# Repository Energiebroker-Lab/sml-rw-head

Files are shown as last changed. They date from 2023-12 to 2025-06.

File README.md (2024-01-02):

# sml-rw-head
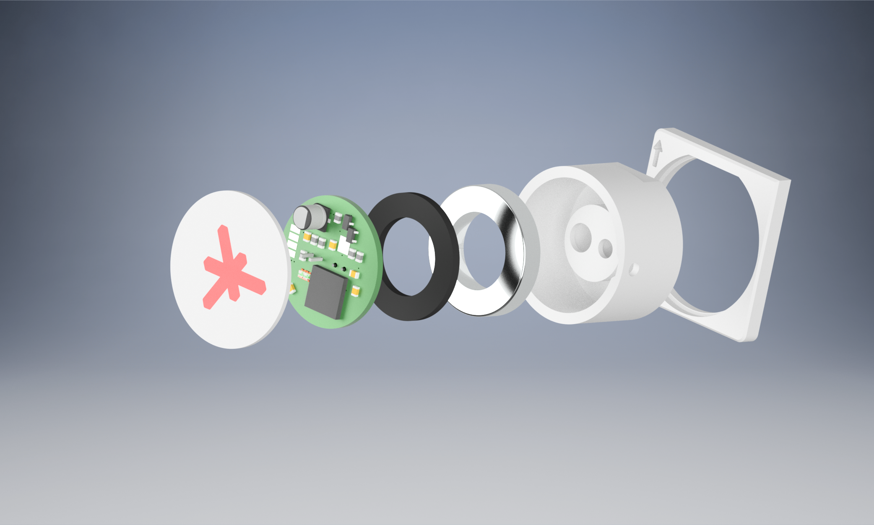
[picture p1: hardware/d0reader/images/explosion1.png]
explosion

## Overview

**sml-rw-head** is a versatile read-write module designed to attach to power meters via a magnet.
It reads the SML (Smart Message Language) or ODT stream from the D0 interface of the meter.
Additionally, the device is equipped to send pulses for entering the PIN or navigating through the menu of the meter
and for example toggle the info mode.

This project encompasses three main components:

1. **Hardware:** Includes schematics and PCB (Printed Circuit Board) designs.
2. **3D-Printable Parts:** Consists of printable components that complement the hardware.
3. **Code:** The code is an implementation example
of the sml-rw-head device.

Each major component has its dedicated directory with its own README.md for detailed information.

## Project Structure

- **Hardware:** The hardware files are located in the `./hardware/d0reader` subdirectory. Refer to the [Hardware README](./hardware/d0reader/README.md) for specifics.

- **3D-Printable Parts:** Find 3D-printable files in the `./hardware/3d-print` subdirectory. More details are available in the [3D-Print README](./hardware/3d-print/README.md).

- **Code:** The source code is in the `./code/sml_rw` subdirectory. To get started with the code, please check the [Code README](./code/sml_rw/README.md).

## Usage

Before using the sml-rw-head module, make sure to review the documentation for each component. Follow the guidelines provided in the respective READMEs for successful integration into your project.

### Preparation
Before using the sml-rw-head module, you need to configure the device using the `ftprog_template.xml` file. Import the file and perform the configuration using the [ftprog](https://ftdichip.com/utilities/) software supplied by FTDI.

## Contributions

Contributions to the sml-rw-head project are welcome! If you have ideas, improvements, or bug fixes, please feel free to submit issues or pull requests.

## License

This project is licensed under the [MIT License](LICENSE). See the LICENSE file for more details.

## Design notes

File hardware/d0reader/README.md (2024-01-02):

Based on https://www.stefan-weigert.de/php_loader/sml.php

# BOM
| Part | Value | Device | Package | Description |
|---|---|---|---|---|
| C1 | 100n | Capacitor | 0805 | Capacitor, Ceramic |
| C2 | 100n | Capacitor | 0805 | Capacitor, Ceramic |
| C3 | 100n | Capacitor | 0805 | Capacitor, Ceramic |
| C4 | 1u | Capacitor | 0805 | Capacitor, Ceramic |
| C5 | 1u | Capacitor | 0805 | Capacitor, Ceramic |
| C6 | 22u | EEEHA1C220R | CPOL-EU153CLV-0505  | 153CLV-0505 POLARIZED CAPACITOR |
| IC1  | FT232RL | FT232RL | SSOP28 | Source: http://www.ftdichip.com/Documents/DataSheets/DS_FT232R_v104.pdf | 
| LED1 | KCL5587S | LED5MM | LED5MM | Infrared-Emitter | 
| LED2 | LEDCHIPLED_0805 | CHIPLED | 0805 | LED (optional) | 
| LED3 | LEDCHIPLED_0805 | CHIPLED | 0805 | LED (optional) | 
| PAD1 | | WIREPADSMD1,27-254 | SMD1,27-2,54 | Wire PAD connect wire on PCB | 
| PAD2 | | WIREPADSMD1,27-254 | SMD1,27-2,54 | Wire PAD connect wire on PCB | 
| PAD3 | | WIREPADSMD1,27-254 | SMD1,27-2,54 | Wire PAD connect wire on PCB | 
| PAD4 | | WIREPADSMD1,27-254 | SMD1,27-2,54 | Wire PAD connect wire on PCB | 
| Q1 | BC817 | BC817-16LT1SMD | SOT23-BEC | NPN Transistor | NPN Transistor | 
| Q2 | SFH_309_FA-4/5  | SFH_309_FA-4/5 | XDCR_SFH_309_FA-4/5 | Phototransistor IR Chip Silicon 900nm 2-Pin T-1 Check prices |
| Q3 | BC817 | BC817-16LT1SMD | SOT23-BEC | NPN Transistor | 
| Q4 | BC817 | BC817-16LT1SMD | SOT23-BEC | NPN Transistor | 
| R1 | 220 | Resistor | 0805 | Resistor |
| R2 | 220 | Resistor | 0805 | Resistor | 
| R3 | 12k | Resistor | 0805 | Resistor | 
| R4 | 12k | Resistor | 0805 | Resistor | 
| R5 | 75 | Resistor | 0805 | Resistor | 
| R6 | 220 | Resistor | 0805 | Resistor | 
| R7 | 220 | Resistor | 0805 | Resistor | 
| U4 | SN74LVC1G17DBVR | Schmitt-Trigger | SOT-23 | Schmitt-Trigger |

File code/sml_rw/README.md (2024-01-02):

TODO: update readmy (new commands + odt)

# sml-reader
Implementation example to read the sml (and odt) data via the d0 interface.

@Python 3.11
# CLI
## Detect 
### all ftdi devices
```commandline
python run.py detect all
```
### single ftdi device
```commandline
python run.py detect serial ftdiSerial
foo@bar:~$ python run.py detect serial EB1337051
```
## Meter
```<meter> => mt681, mt175, ehz, easy, dd3_sml, dd3_sml_2way, dd3_odt, dd3_odt_2way```
### log bytes to file
```commandline
python run.py <meter> log_bytes ftdiSerial
foo@bar:~$ python run.py mt175 log_bytes EB1337051
``` 
### log sml to cli
```commandline
python run.py <meter> log_cli ftdiSerial
foo@bar:~$ python run.py mt175 log_cli EB1337051
``` 
### log sml to file
```commandline
python run.py <meter> log_sml ftdiSerial
foo@bar:~$ python run.py mt175 log_sml EB1337051
``` 
### enter pin
```commandline
python run.py <meter> pin ftdiSerial pin
foo@bar:~$ python run.py mt175 pin EB1337051 [1,2,3,4]
``` 
### clear history data (only dd3 and easy meters)
#### topics
* e
* his
```commandline
python run.py <meter> clear ftdiSerial pin topic
foo@bar:~$ python run.py dd3 clear EB1337051 [1,2,3,4] e
``` 
### show (only dd3 and easy meters)
#### topics
* e
* 1d
* 7d
* 30d
* 365d
* info
* p
* pin
```commandline
python run.py <meter> show ftdiSerial pin topic
foo@bar:~$ python run.py dd3 show EB1337051 [1,2,3,4] e
``` 
### toggle (only dd3 and easy meters)
#### topics
* info
* p
* pin
```commandline
python run.py <meter> toggle ftdiSerial pin topic
foo@bar:~$ python run.py dd3 toggle EB1337051 [1,2,3,4] info
``` 
### interactive mode
#### interactive commands
* short pulse -> .
* long pulse -> -
* pause -> _space_
* quit interactive mode -> exit
```commandline
python run.py <meter> interactive ftdiSerial pin
foo@bar:~$ python run.py dd3 interactive EB1337051 [1,2,3,4]
```

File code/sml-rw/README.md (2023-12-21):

# sml-reader
Implementation example to read the sml data via the d0 interface. Sample data included.

@Python 3.9
# cli
## detect 
### all ftdi devices
```commandline
python run.py detect all
```
### single ftdi device
```commandline
python run.py detect serial ftdiSerial
foo@bar:~$ python run.py detect serial EB_DE_PROT_3
```
## Meter: mt175
### log bytes to file
```commandline
python run.py mt175 logBytes ftdiSerial
foo@bar:~$ python run.py mt175 logBytes EB_DE_PROT_3
``` 
### log sml to cli
```commandline
python run.py mt175 logCli ftdiSerial
foo@bar:~$ python run.py mt175 logCli EB_DE_PROT_3
``` 
### log sml to file
```commandline
python run.py mt175 logSml ftdiSerial
foo@bar:~$ python run.py mt175 logSml EB_DE_PROT_3
``` 
### enter pin
```commandline
python run.py mt175 pin ftdiSerial pin
foo@bar:~$ python run.py mt175 pin EB_DE_PROT_3 [1,2,3,4]
``` 
## Meter: mt681
### log bytes to file
```commandline
python run.py mt681 logBytes ftdiSerial
foo@bar:~$ python run.py mt681 logBytes EB_DE_PROT_3
``` 
### log sml to cli
```commandline
python run.py mt681 logCli ftdiSerial
foo@bar:~$ python run.py mt681 logCli EB_DE_PROT_3
``` 
### log sml to file
```commandline
python run.py mt681 logSml ftdiSerial
foo@bar:~$ python run.py mt681 logSml EB_DE_PROT_3
``` 
### enter pin
```commandline
python run.py mt681 pin ftdiSerial pin
foo@bar:~$ python run.py mt681 pin EB_DE_PROT_3 [1,2,3,4]
``` 
## Meter: ehz
### log bytes to file
```commandline
python run.py ehz logBytes ftdiSerial
foo@bar:~$ python run.py ehz logBytes EB_DE_PROT_3
``` 
### log sml to cli
```commandline
python run.py ehz logCli ftdiSerial
foo@bar:~$ python run.py ehz logCli EB_DE_PROT_3
``` 
### log sml to file
```commandline
python run.py ehz logSml ftdiSerial
foo@bar:~$ python run.py ehz logSml EB_DE_PROT_3
``` 
### enter pin
```commandline
python run.py ehz pin ftdiSerial pin
foo@bar:~$ python run.py ehz pin EB_DE_PROT_3 [1,2,3,4]
``` 
## Meter: dd3
### log bytes to file
```commandline
python run.py dd3 logBytes ftdiSerial
foo@bar:~$ python run.py dd3 logBytes EB_DE_PROT_3
``` 
### log sml to cli
```commandline
python run.py dd3 logCli ftdiSerial
foo@bar:~$ python run.py dd3 logCli EB_DE_PROT_3
``` 
### log sml to file
```commandline
python run.py dd3 logSml ftdiSerial
foo@bar:~$ python run.py dd3 logSml EB_DE_PROT_3
``` 
### enter pin
```commandline
python run.py dd3 pin ftdiSerial pin
foo@bar:~$ python run.py dd3 pin EB_DE_PROT_3 [1,2,3,4]
``` 
### clear history data
#### topics
* e
* his
```commandline
python run.py dd3 clear ftdiSerial pin topic
foo@bar:~$ python run.py dd3 clear EB_DE_PROT_3 [1,2,3,4] e
``` 
### show
#### topics
* e
* 1d
* 7d
* 30d
* 365d
* info
* p
* pin
```commandline
python run.py dd3 show ftdiSerial pin topic
foo@bar:~$ python run.py dd3 show EB_DE_PROT_3 [1,2,3,4] e
``` 
### toggle
#### topics
* info
* p
* pin
```commandline
python run.py dd3 toggle ftdiSerial pin topic
foo@bar:~$ python run.py dd3 toggle EB_DE_PROT_3 [1,2,3,4] info
``` 
### interactive mode
#### interactive commands
* short pulse -> .
* long pulse -> -
* pause -> _space_
* quit interactive mode -> exit
```commandline
python run.py dd3 interactive ftdiSerial pin
foo@bar:~$ python run.py dd3 interactive EB_DE_PROT_3 [1,2,3,4]
``` 
## Meter: EasyMeter
### log bytes to file
```commandline
python run.py easy logBytes ftdiSerial
foo@bar:~$ python run.py easy logBytes EB_DE_PROT_3
``` 
### log sml to cli
```commandline
python run.py easy logCli ftdiSerial
foo@bar:~$ python run.py easy logCli EB_DE_PROT_3
``` 
### log sml to file
```commandline
python run.py easy logSml ftdiSerial
foo@bar:~$ python run.py easy logSml EB_DE_PROT_3
``` 
### enter pin
```commandline
python run.py easy pin ftdiSerial pin
foo@bar:~$ python run.py easy pin EB_DE_PROT_3 [1,2,3,4]
``` 
### clear history data
#### topics
* e
* his
```commandline
python run.py easy clear ftdiSerial pin topic
foo@bar:~$ python run.py easy clear EB_DE_PROT_3 [1,2,3,4] e
``` 
### show
#### topics
* e
* 1d
* 7d
* 30d
* 365d
* info
* p
* pin
```commandline
python run.py easy show ftdiSerial pin topic
foo@bar:~$ python run.py easy show EB_DE_PROT_3 [1,2,3,4] e
``` 
### toggle
#### topics
* info
* p
* pin
```commandline
python run.py easy toggle ftdiSerial pin topic
foo@bar:~$ python run.py easy toggle EB_DE_PROT_3 [1,2,3,4] info
``` 
### interactive mode
#### interactive commands
* short pulse -> .
* long pulse -> -
* pause -> _space_
* quit interactive mode -> exit
```commandline
python run.py easy interactive ftdiSerial pin
foo@bar:~$ python run.py easy interactive EB_DE_PROT_3 [1,2,3,4]
```

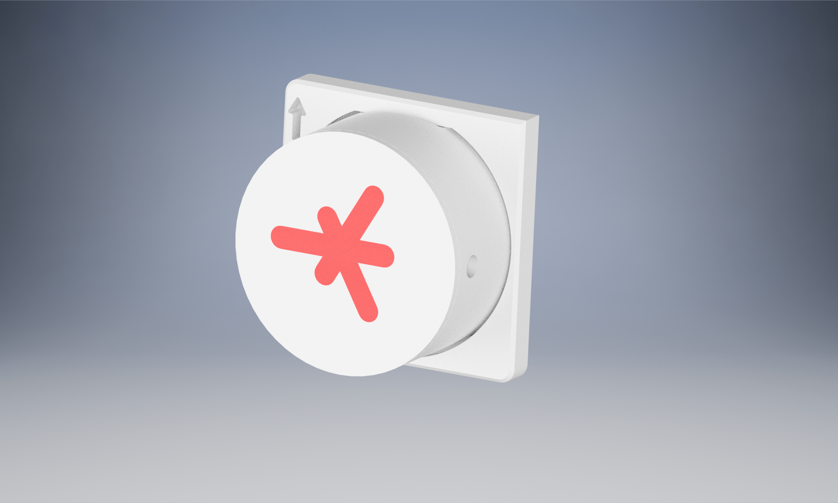
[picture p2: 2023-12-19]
hardware/d0reader/images/front.png

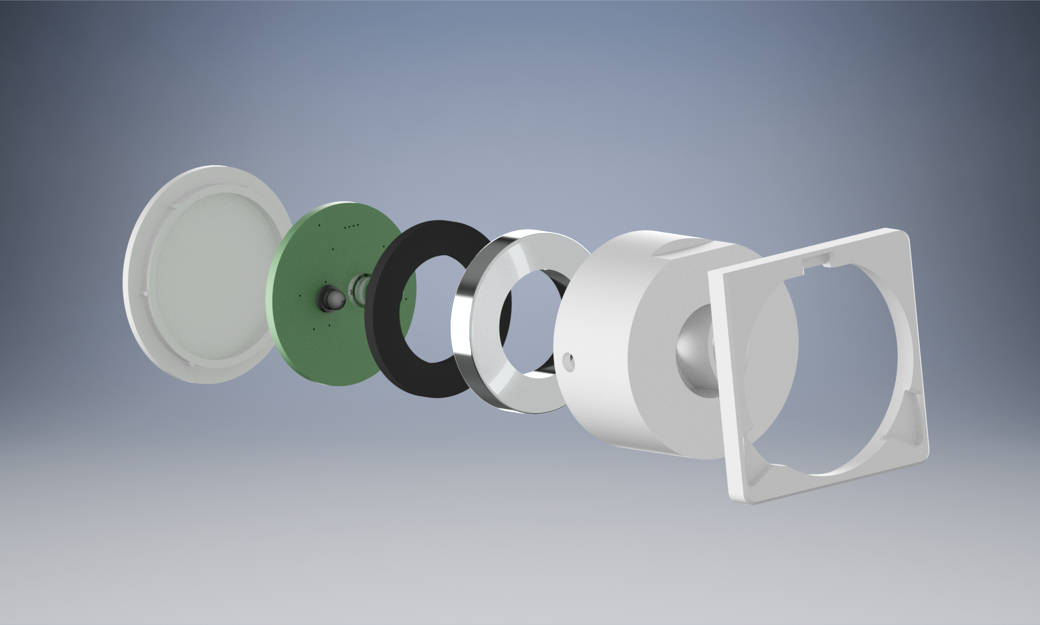
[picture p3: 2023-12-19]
hardware/d0reader/images/explosion2.png

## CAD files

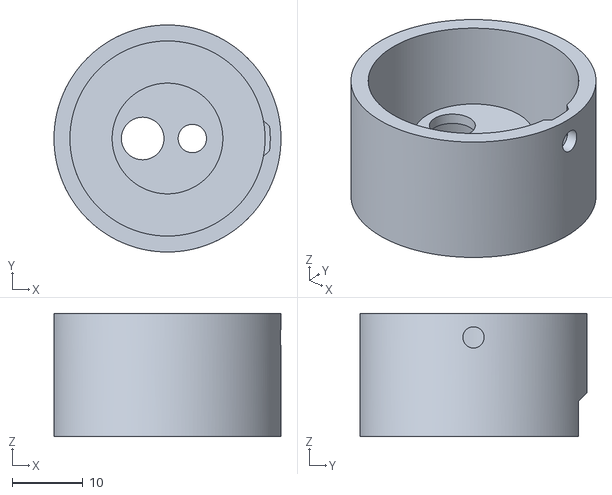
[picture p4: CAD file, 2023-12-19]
hardware/3d-print/case/body.stl
32.0 x 32.0 x 17.4

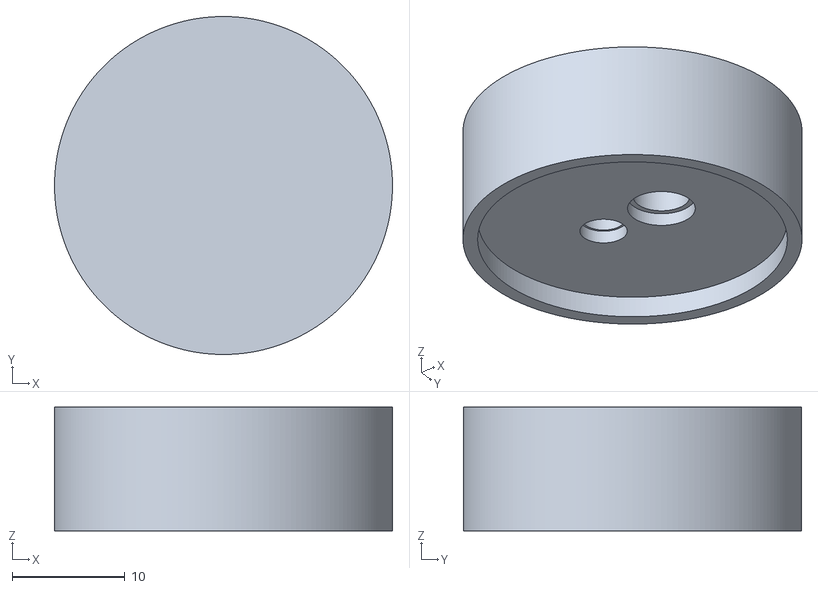
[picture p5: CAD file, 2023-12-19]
hardware/3d-print/depth_stencil.stl
30.0 x 30.0 x 11.0

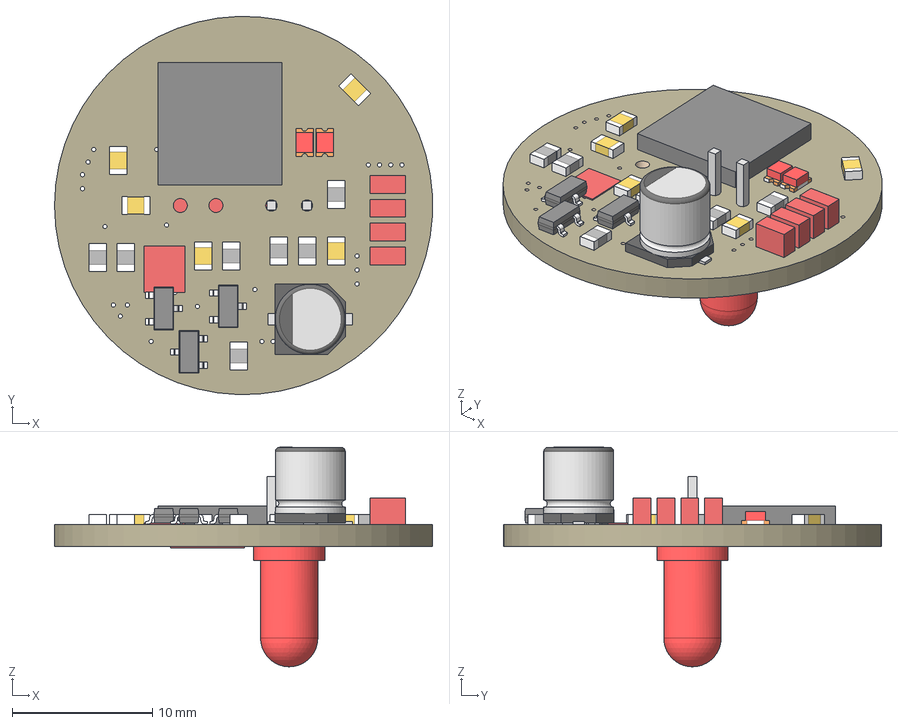
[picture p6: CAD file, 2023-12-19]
hardware/d0reader/3d/d0reader.stp
27.0 x 27.0 x 15.7 mm
Board
100n x 5
KCL5587S
CHIPLED_0805 x 2
SFH_309_FA-4/5
22u EEEHA1C220R
BC817-16LT1SMD x 3
SN74LVC1G17DBVR
FT232RL
WIREPADSMD1,27-254 x 4

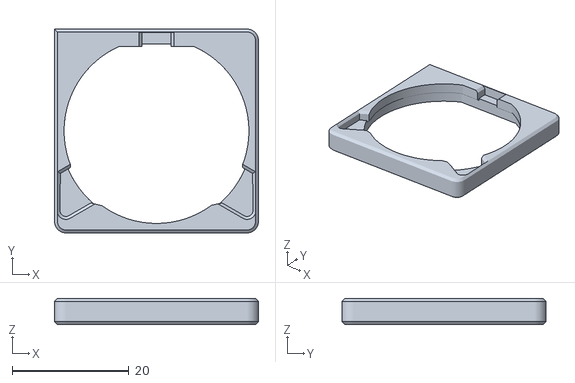
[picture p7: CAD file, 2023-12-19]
hardware/3d-print/case/centering_aid.stl
35.0 x 35.0 x 4.50

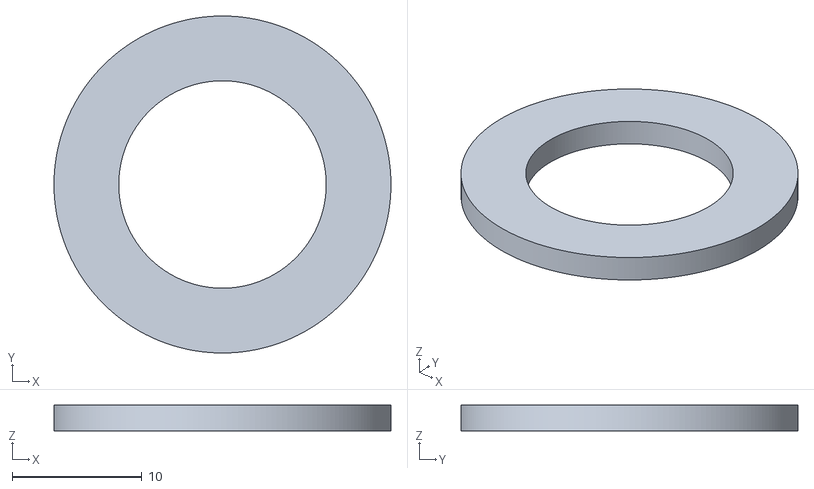
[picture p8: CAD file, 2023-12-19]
hardware/3d-print/case/spacer.stl
26.0 x 26.0 x 2.00

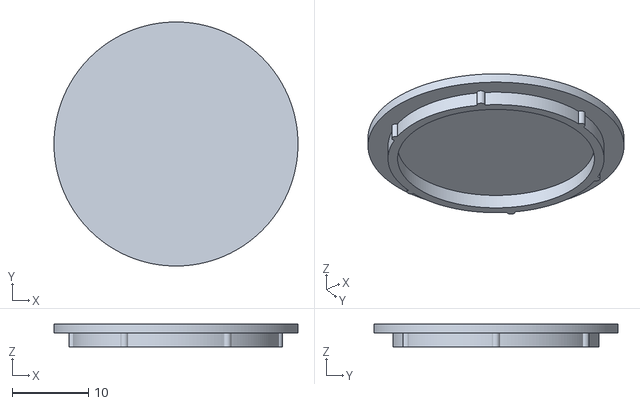
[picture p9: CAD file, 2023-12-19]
hardware/3d-print/case/lid.stl
32.0 x 32.0 x 3.00

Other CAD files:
hardware/3d-print/case/body.ipt
hardware/3d-print/case/centering_aid.ipt
hardware/3d-print/case/lid.ipt
hardware/3d-print/case/spacer.ipt
hardware/3d-print/depth_stencil.ipt
hardware/d0reader/3d/d0reader.stl

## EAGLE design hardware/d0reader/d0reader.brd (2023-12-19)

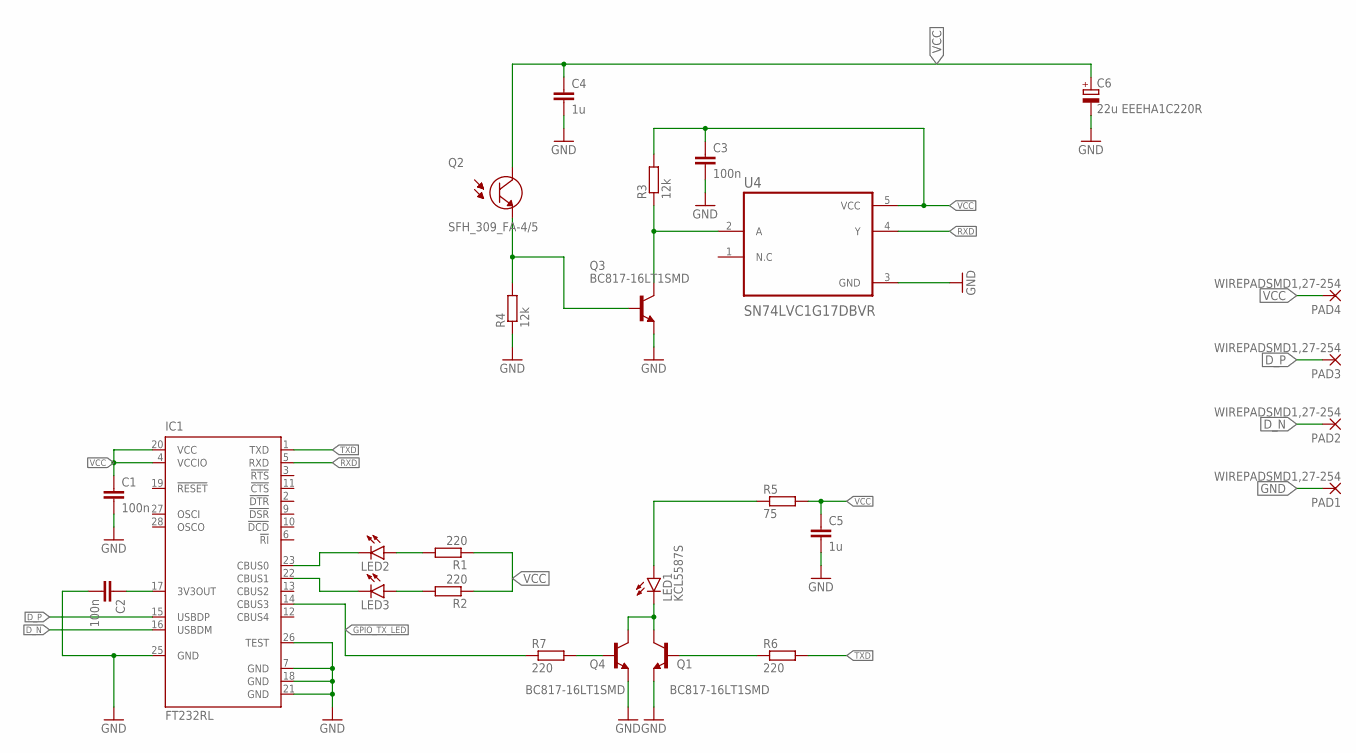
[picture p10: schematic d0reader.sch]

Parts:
C1, C2, C3: 100n; C0805
C4, C5: 1u; C0805
C6: 22u EEEHA1C220R; 153CLV-0505
IC1: FT232RL; SSOP28
LED1: KCL5587S; LED5MM
LED2, LED3: LEDCHIPLED_0805; CHIPLED_0805
PAD1, PAD2, PAD3, PAD4: WIREPADSMD1,27-254; SMD1,27-2,54
Q1, Q3, Q4: BC817-16LT1SMD; SOT23-BEC
Q2: SFH_309_FA-4/5; XDCR_SFH_309_FA-4/5
R1, R2, R6, R7: 220; R0805
R3, R4: 12k; R0805
R5: 75; R0805
U4: SN74LVC1G17DBVR; SOT95P280X145-5N

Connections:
D_N: IC1.16 (USBDM), PAD2.1
D_P: IC1.15 (USBDP), PAD3.1
GND: C1.2, C2.2, C3.2, C4.2, C5.2, C6.-, IC1.7 (GND), IC1.18 (GND), IC1.21 (GND), IC1.25 (GND), IC1.26 (TEST), PAD1.1, Q1.E, Q3.E, Q4.E, R4.1, U4.3 (GND)
GPIO_TX_LED: IC1.14 (CBUS3), R7.1
INPUTA: Q3.C, R3.1, U4.2 (A)
unnamed: LED2.A, R1.2
unnamed: LED3.A, R2.2
unnamed: C2.1, IC1.17 (3V3OUT)
OPTO_RX: Q2.1 (E), Q3.B, R4.2
RXD: IC1.5 (RXD), U4.4 (Y)
RXLED: IC1.22 (CBUS1), LED3.C
TXD: IC1.1 (TXD), R6.2
TXLED: IC1.23 (CBUS0), LED2.C
TXLEDGND: LED1.K (C), Q1.C, Q4.C
TXLEDVCC: LED1.A, R5.1
TX_LED_Q1: Q1.B, R6.1
TX_LED_Q4: Q4.B, R7.2
VCC: C1.1, C3.1, C4.1, C5.1, C6.+, IC1.4 (VCCIO), IC1.20 (VCC), PAD4.1, Q2.2 (C), R1.1, R2.1, R3.2, R5.2, U4.5 (VCC)

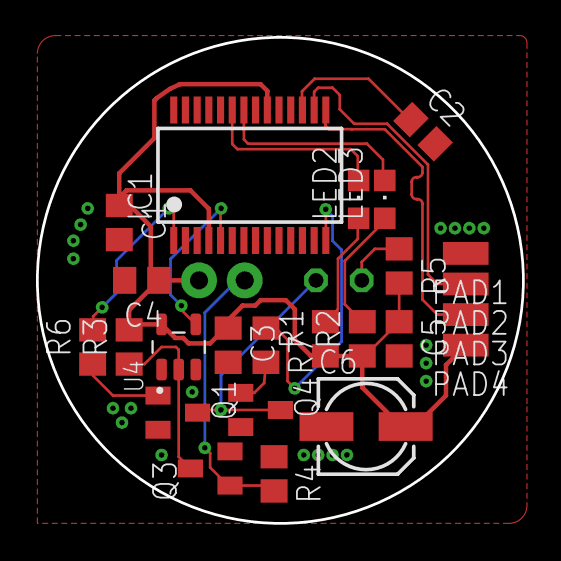
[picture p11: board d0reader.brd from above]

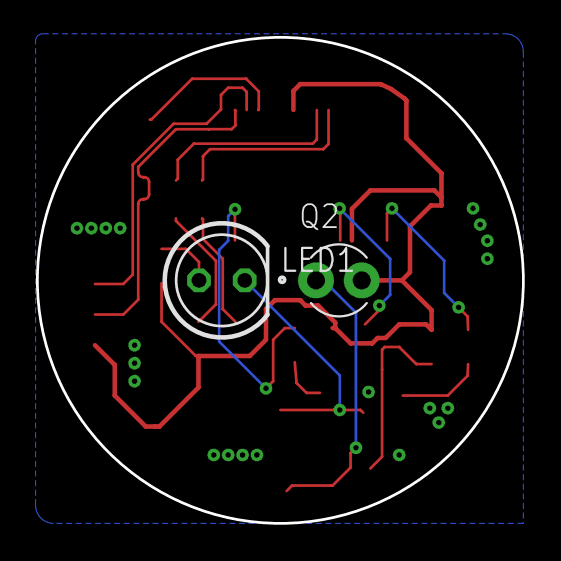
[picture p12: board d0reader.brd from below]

Board: 2 copper layers, 27.0 x 27.0 mm, 26 parts (2 on the bottom side), 18 nets.

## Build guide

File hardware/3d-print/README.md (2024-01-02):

# Depth stencil
The depth stencil is used to adjust the depth of the LED and the phototransistor
to match the printed housing before soldering.

To do this, the components are placed on the circuit board, and then the entire assembly, including the circuit board,
is placed on the depth stencil. The holes in the stencil have different diameters, so the LED and the phototransistor
must be pressed into the respective correct holes.

The depth stencil also serves as a soldering aid and can be fixed
to the table, for example, with double-sided tape.

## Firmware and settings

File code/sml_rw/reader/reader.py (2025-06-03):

"""
sml reader
"""
import sys
import traceback
from threading import Timer
import serial
import smllib
from loguru import logger
from detect import DetectSerial
from meters.meter import ConnectionSettings, TelegramType
from odt.odt_frame import OdtFrame


class WatchdogTimer:
    """
    used to separate sml streams
    """

    def __init__(self, timeout: float, user_handler=None):
        self.timeout = timeout
        self.handler = user_handler if user_handler is not None else self.default_handler
        self.timer = Timer(self.timeout, self.handler)
        self.timer.start()

    def reset(self):
        """
        resets the timer
        """
        self.timer.cancel()
        self.timer = Timer(self.timeout, self.handler)
        self.timer.start()

    def stop(self):
        """
        stops the timer
        """
        self.timer.cancel()

    def default_handler(self):
        """
        no handler supplied -> raises Exception
        """
        raise AttributeError


# pylint: disable=too-many-arguments, too-many-instance-attributes
class SmlReader:
    """
    reader class
    """
    bytes_buffer = b''
    crc16_x25_table = [
        0x0000, 0x1189, 0x2312, 0x329B, 0x4624, 0x57AD, 0x6536, 0x74BF,
        0x8C48, 0x9DC1, 0xAF5A, 0xBED3, 0xCA6C, 0xDBE5, 0xE97E, 0xF8F7,
        0x1081, 0x0108, 0x3393, 0x221A, 0x56A5, 0x472C, 0x75B7, 0x643E,
        0x9CC9, 0x8D40, 0xBFDB, 0xAE52, 0xDAED, 0xCB64, 0xF9FF, 0xE876,
        0x2102, 0x308B, 0x0210, 0x1399, 0x6726, 0x76AF, 0x4434, 0x55BD,
        0xAD4A, 0xBCC3, 0x8E58, 0x9FD1, 0xEB6E, 0xFAE7, 0xC87C, 0xD9F5,
        0x3183, 0x200A, 0x1291, 0x0318, 0x77A7, 0x662E, 0x54B5, 0x453C,
        0xBDCB, 0xAC42, 0x9ED9, 0x8F50, 0xFBEF, 0xEA66, 0xD8FD, 0xC974,
        0x4204, 0x538D, 0x6116, 0x709F, 0x0420, 0x15A9, 0x2732, 0x36BB,
        0xCE4C, 0xDFC5, 0xED5E, 0xFCD7, 0x8868, 0x99E1, 0xAB7A, 0xBAF3,
        0x5285, 0x430C, 0x7197, 0x601E, 0x14A1, 0x0528, 0x37B3, 0x263A,
        0xDECD, 0xCF44, 0xFDDF, 0xEC56, 0x98E9, 0x8960, 0xBBFB, 0xAA72,
        0x6306, 0x728F, 0x4014, 0x519D, 0x2522, 0x34AB, 0x0630, 0x17B9,
        0xEF4E, 0xFEC7, 0xCC5C, 0xDDD5, 0xA96A, 0xB8E3, 0x8A78, 0x9BF1,
        0x7387, 0x620E, 0x5095, 0x411C, 0x35A3, 0x242A, 0x16B1, 0x0738,
        0xFFCF, 0xEE46, 0xDCDD, 0xCD54, 0xB9EB, 0xA862, 0x9AF9, 0x8B70,
        0x8408, 0x9581, 0xA71A, 0xB693, 0xC22C, 0xD3A5, 0xE13E, 0xF0B7,
        0x0840, 0x19C9, 0x2B52, 0x3ADB, 0x4E64, 0x5FED, 0x6D76, 0x7CFF,
        0x9489, 0x8500, 0xB79B, 0xA612, 0xD2AD, 0xC324, 0xF1BF, 0xE036,
        0x18C1, 0x0948, 0x3BD3, 0x2A5A, 0x5EE5, 0x4F6C, 0x7DF7, 0x6C7E,
        0xA50A, 0xB483, 0x8618, 0x9791, 0xE32E, 0xF2A7, 0xC03C, 0xD1B5,
        0x2942, 0x38CB, 0x0A50, 0x1BD9, 0x6F66, 0x7EEF, 0x4C74, 0x5DFD,
        0xB58B, 0xA402, 0x9699, 0x8710, 0xF3AF, 0xE226, 0xD0BD, 0xC134,
        0x39C3, 0x284A, 0x1AD1, 0x0B58, 0x7FE7, 0x6E6E, 0x5CF5, 0x4D7C,
        0xC60C, 0xD785, 0xE51E, 0xF497, 0x8028, 0x91A1, 0xA33A, 0xB2B3,
        0x4A44, 0x5BCD, 0x6956, 0x78DF, 0x0C60, 0x1DE9, 0x2F72, 0x3EFB,
        0xD68D, 0xC704, 0xF59F, 0xE416, 0x90A9, 0x8120, 0xB3BB, 0xA232,
        0x5AC5, 0x4B4C, 0x79D7, 0x685E, 0x1CE1, 0x0D68, 0x3FF3, 0x2E7A,
        0xE70E, 0xF687, 0xC41C, 0xD595, 0xA12A, 0xB0A3, 0x8238, 0x93B1,
        0x6B46, 0x7ACF, 0x4854, 0x59DD, 0x2D62, 0x3CEB, 0x0E70, 0x1FF9,
        0xF78F, 0xE606, 0xD49D, 0xC514, 0xB1AB, 0xA022, 0x92B9, 0x8330,
        0x7BC7, 0x6A4E, 0x58D5, 0x495C, 0x3DE3, 0x2C6A, 0x1EF1, 0x0F78
    ]

    def __init__(
            self,
            ftdi_serial,
            log_sml: bool = False,
            log_bytes: bool = False,
            log_file='reader.log',
            connection_settings: ConnectionSettings = None,
            telegram_type: TelegramType = 'sml'
    ):
        self.ftdi_serial = ftdi_serial
        self.log_sml = log_sml
        self.log_bytes = log_bytes
        self.log_file = log_file
        self.connection_settings = connection_settings
        self.telegram_type = telegram_type
        self._stream = smllib.SmlStreamReader()
        self._odt_stream = OdtFrame()

    def watchdog_timer_ovf(self, only_obis: bool = False):
        """
        Called when the sml stream ends
        :param only_obis: True -> extrace only the obis values
        """
        if self.telegram_type == TelegramType.ODT:
            sml = self._odt_stream.to_sml()
            for character in sml:
                self._stream.add(character.to_bytes(length=1, byteorder='big'))

        if self.log_bytes:
            with open(self.log_file, "ab") as myfile:
                myfile.write(self.bytes_buffer)
        self._stream.add(self.bytes_buffer)
        sml_frame = self._stream.get_frame()
        if sml_frame is None:
            logger.info('Bytes missing')
            return

        if only_obis:
            # Shortcut to extract all values without parsing the whole frame
            obis_values = sml_frame.get_obis()
            for msg in obis_values:
                # prints a nice overview over the received values
                logger.info('Obis: {}', msg.get_value())

        else:
            # return all values but slower
            parsed_msgs = sml_frame.parse_frame()
            for msg in parsed_msgs:
                # prints a nice overview over the received values
                logger.info('Frame: {}', msg.format_msg())
                if self.log_sml:
                    with open(self.log_file, "a", encoding="utf-8") as myfile:
                        myfile.write(msg.format_msg())

    def run(self):
        """
        starts listening to the stream
        """
        try:
            detect_serial = DetectSerial(ftdi_serial=self.ftdi_serial)  # Seriennummer der Lesekopfs
            device_tty = serial.Serial(
                port=detect_serial.get_port(),
                timeout=0,
                **self.connection_settings
            )
            logger.info(device_tty.portstr + " geöffnet\n\n")
            device_tty.close()
            device_tty.open()
            try:
                device_tty.reset_input_buffer()
                device_tty.reset_output_buffer()
                watchdog = WatchdogTimer(0.1, self.watchdog_timer_ovf)
                watchdog.stop()
                while True:
                    while device_tty.in_waiting > 0:
                        # self.bytes_buffer += device_tty.read()
                        byte = device_tty.read(size=1)
                        match self.telegram_type:
                            case TelegramType.SML:
                                self._stream.add(byte)
                            case TelegramType.ODT:
                                self._odt_stream.add(byte)
                        watchdog.reset()

            except KeyboardInterrupt:
                device_tty.close()
                logger.info("\nProgramm wurde manuell beendet!\n")
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

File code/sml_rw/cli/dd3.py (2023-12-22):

"""
DD3 meter cli
"""
from typing import List, Annotated

from loguru import logger

from meters.dd3_odt import DD3ODT
from meters.dd3_odt_2way import DD3ODT2Way
from meters.dd3_sml import DD3SML
from meters.dd3_sml_2way import DD3SML2Way
from reader.reader import SmlReader


# pylint: disable=protected-access
class Dd3Cli:
    """
    DD3 meter cli arguments
    """
    meter = None

    def get_meter(self, ftdi_serial: str, pin: Annotated[List[int], 4]):
        """
        stores a meter instance in self.meter
        """
        raise NotImplementedError

    def log_cli(self, ftdi_serial: str):
        """
        logs sml to the stdout
        :param ftdi_serial: serial number of the ftdi device
        """
        logger.info('logCli mode')
        self.get_meter(ftdi_serial, [0, 0, 0, 0])
        if self.meter is None:
            logger.error("Meter instance not initialized")
            return
        sml_reader = SmlReader(
            ftdi_serial,
            connection_settings=self.meter.connection_settings,
            telegram_type=self.meter.telegram_type
        )
        sml_reader.run()
        del self.meter

    def log_sml(self, ftdi_serial: str):
        """
        logs sml to logfile
        :param ftdi_serial: serial number of the ftdi device
        """
        logger.info('log_sml mode')
        self.get_meter(ftdi_serial, [0, 0, 0, 0])
        if self.meter is None:
            logger.error("Meter instance not initialized")
            return
        sml_reader = SmlReader(
            ftdi_serial,
            log_sml=True,
            log_file='logSmlDd3.log',
            connection_settings=self.meter.connection_settings,
            telegram_type=self.meter.telegram_type
        )

        sml_reader.run()
        del self.meter

    def log_bytes(self, ftdi_serial: str):
        """
        logs bytes to logfile
        :param ftdi_serial: serial number of the ftdi device
        """
        logger.info('log_bytes mode')
        self.get_meter(ftdi_serial, [0, 0, 0, 0])
        if self.meter is None:
            logger.error("Meter instance not initialized")
            return
        byte_reader = SmlReader(
            ftdi_serial,
            log_bytes=True,
            log_file='logBytesDd3.log',
            connection_settings=self.meter.connection_settings,
            telegram_type=self.meter.telegram_type
        )
        byte_reader.run()
        del self.meter

    def pin(self, ftdi_serial: str, pin: Annotated[List[int], 4]):
        """
        enters pin of the meter
        :param ftdi_serial: serial number of the ftdi device
        :param pin: the pin of the meter
        """
        self.get_meter(ftdi_serial, pin)
        if self.meter is None:
            logger.error("Meter instance not initialized")
            return
        self.meter.set_debug(True)
        self.meter.enter_pin()
        del self.meter

    def clear(self, ftdi_serial: str, pin: Annotated[List[int], 4], topic: str):
        """
        clears the history of the supplied topic
        :param ftdi_serial: serial number of the ftdi device
        :param pin: the pin of the meter
        :param topic: e or his
        """
        self.get_meter(ftdi_serial, pin)
        if self.meter is None:
            logger.error("Meter instance not initialized")
            return
        self.meter.set_debug(True)
        if topic == 'e':
            self.meter.clear('e')
        elif topic == 'his':
            self.meter.toggle('his')
        del self.meter

    def show(self, ftdi_serial: str, pin: Annotated[List[int], 4], topic: str):
        """
        shows the supplied topic
        :param ftdi_serial: serial number of the ftdi device
        :param pin: the pin of the meter
        :param topic: the topic (menu_item)
        """
        self.get_meter(ftdi_serial, pin)
        if self.meter is None:
            logger.error("Meter instance not initialized")
            return
        self.meter.set_debug(True)
        self.meter.show(topic)
        del self.meter

    def toggle(self, ftdi_serial: str, pin: Annotated[List[int], 4], topic: str):
        """
        toggles the supplied topic (menu_item)
        :param ftdi_serial: serial number of the ftdi device
        :param pin: the pin of the meter
        :param topic: info, p or pin
        """
        self.get_meter(ftdi_serial, pin)
        if self.meter is None:
            logger.error("Meter instance not initialized")
            return
        self.meter.set_debug(True)
        self.meter.toggle(topic)
        del self.meter

    def interactive(self, ftdi_serial: str, pin: Annotated[List[int], 4]):
        """
        interactive control mode
        :param ftdi_serial: serial number of the ftdi device
        :param pin: the pin of the meter
        """
        try:
            self.get_meter(ftdi_serial, pin)
            if self.meter is None:
                logger.error("Meter instance not initialized")
                return
            self.meter.set_debug(True)
            self.meter.enter_pin()
            print("'exit' to quit")
            exit_loop = False
            while not exit_loop:
                pulse = input("'.' = short pulse, '-' = long pulse, ' ' = pause:")
                for c in pulse:
                    if c == ".":
                        print("sending short pulse")
                        self.meter._short_pulse()
                    elif c == "-":
                        print("sending long pulse")
                        self.meter._long_pulse()
                    elif c == " ":
                        print("sending pause")
                        self.meter._pause()
                    elif c == "exit":
                        exit_loop = True
            del self.meter
        except KeyboardInterrupt:
            if self.meter:
                del self.meter
            logger.info("\nProgramm wurde manuell beendet!\n")


class Dd3CliSML(Dd3Cli):
    """
    DD3 meter SML
    """
    meter = None

    def get_meter(self, ftdi_serial: str, pin: Annotated[List[int], 4]):
        """
        stores a meter instance in self.meter
        """
        self.meter = DD3SML(ftdi_serial, pin)


class Dd3CliSML2Way(Dd3Cli):
    """
    DD3 meter SML two-way
    """
    meter = None

    def get_meter(self, ftdi_serial: str, pin: Annotated[List[int], 4]):
        """
        stores a meter instance in self.meter
        """
        self.meter = DD3SML2Way(ftdi_serial, pin)


class Dd3CliODT(Dd3Cli):
    """
    DD3 meter ODT
    """
    meter = None

    def get_meter(self, ftdi_serial: str, pin: Annotated[List[int], 4]):
        """
        stores a meter instance in self.meter
        """
        self.meter = DD3ODT(ftdi_serial, pin)
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
